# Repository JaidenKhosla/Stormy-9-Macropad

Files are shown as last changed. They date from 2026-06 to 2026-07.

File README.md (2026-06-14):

# Stormy 9 - A Macropad Designed for Simplicity
## *In today's age of mechanical keyboards, people value simplicity and customizability. The Stormy 9 allows this by having up to 16 programmable buttons, a knob to adjust volume and brightness, and an OLED display that shows off your WPM and a cute picture of my cat (non-negotiable).*

### \* *The case is mounted from the bottom. In my current setup, a top mounted case would look bad (not saying top mounted cases look ugly or anything, it just wouldn't work for my personal setup).*

## Personal Use:
####  A bit off topic, but I'm probably going to use this macropad for additional keybinds for video games (probably CS2 with their buy menu). Also, I've always desired to adjust my volume and brightness with ease as my current keyboard doesn't have a knob.

## PCB Schematic (Made with KICAD)
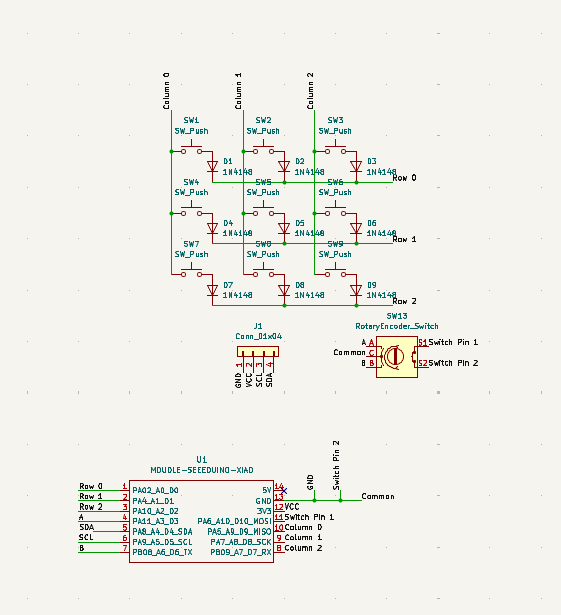
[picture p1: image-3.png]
 

#### I learned PCB schematics through ScottoKeeb's tutorial (https://youtu.be/8WXpGTIbxlQ?si=Y5YSVLcabkqrECWy). It was genuinely super helpful and I would've spent so many more hours without it.

## PCB Layout
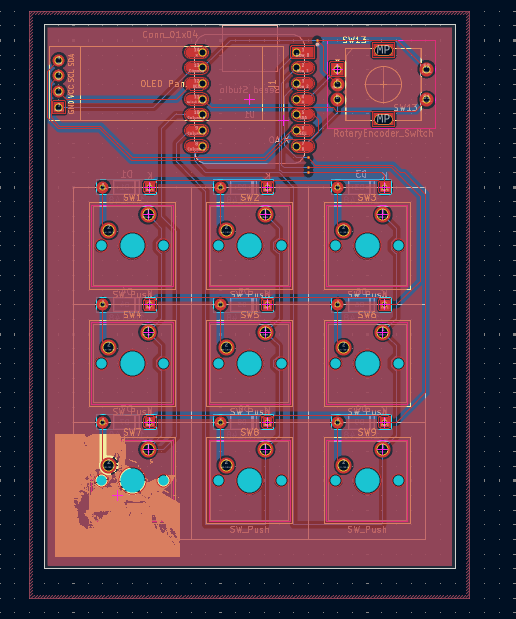
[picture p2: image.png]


## 3D Model of The Stormy 9
#### For context, I tried using Fusion-360 to design the case (like any normal person would). However, Fusion-360 refused to import STEP and STL files (I wanted to import the 3D model of my PCB for rendering and ease of modeling), forcing me to voluntarily choose Blender. Contrary to popular belief, Blender was actually super easy and useful to model the case. For anyone planning to design their case in Blender, please google what non-manifold edges are before starting (it will save you so much time in the future). To convert the models to STEP files, I utilized the open-sourced software, FreeCAD.
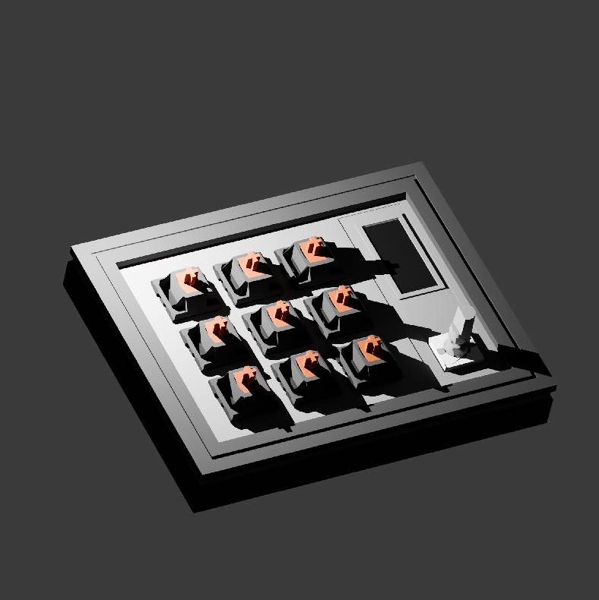
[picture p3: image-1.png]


## 3D render of the backside of the Stormy 9
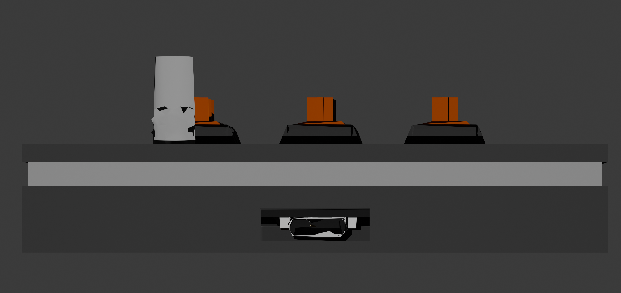
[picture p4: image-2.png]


## Firmware
### For the firmware, I utilized the open-source project, QMK. I found this to be a lot better than KMK as it's still officially maintained and gave developers a lot more granular control. It also forces you to code in C rather than Python (Take that as a bonus or a burden). 

# __Materials Needed:__
### * 1 Seeed XIAO RP2040 Microcontroller
### * 9 1N4148 Through-Hole Diodes
### * 9 MX-style Mechanical Switches
### * 1 EC11 Rotary Encoder
### * 1 0.91" 128X32 OLED Display
### * 9 Blank DSA Keycaps
### * 4 M3x16mm Screws
### * 4 M3x5x4mm Heatset Inserts
### * Sanity

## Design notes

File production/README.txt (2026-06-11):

When I was debugging the 3D models in their STEP formats with Creality Print, TOP_CASE_PRINT_V2.STEP when sliced produced something that would've messed up the entire macropad. When you import it as an STL, it slices correctly. I included the STEP file, but please use the STL file.

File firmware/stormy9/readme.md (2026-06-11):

# stormy9

stormy9

*A short description of the keyboard/project*

* Keyboard Maintainer: [Jaiden Khosla](https://github.com/JaidenKhosla)
* Hardware Supported: *The PCBs, controllers supported*
* Hardware Availability: *Links to where you can find this hardware*

Make example for this keyboard (after setting up your build environment):

    make stormy9:default

Flashing example for this keyboard:

    make stormy9:default:flash

See the [build environment setup](https://docs.qmk.fm/#/getting_started_build_tools) and the [make instructions](https://docs.qmk.fm/#/getting_started_make_guide) for more information. Brand new to QMK? Start with our [Complete Newbs Guide](https://docs.qmk.fm/#/newbs).

## Bootloader

Enter the bootloader in 3 ways:

* **Bootmagic reset**: Hold down the key at (0,0) in the matrix (usually the top left key or Escape) and plug in the keyboard
* **Physical reset button**: Briefly press the button on the back of the PCB - some may have pads you must short instead
* **Keycode in layout**: Press the key mapped to `QK_BOOT` if it is available

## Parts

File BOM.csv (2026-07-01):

Name | Quantity
Seeed XIAO RP2040 Microcontroller | 1
1N4148 Through-Hole Diodes | 9
MX-style Mechanical Switches | 9
EC11 Rotary Encoder | 1
0.91" 128x32 OLED Display | 1
Blank DSA Keycaps | 9
M3x16mm Screws | 4
M3x5x4mm Heatset Inserts | 4

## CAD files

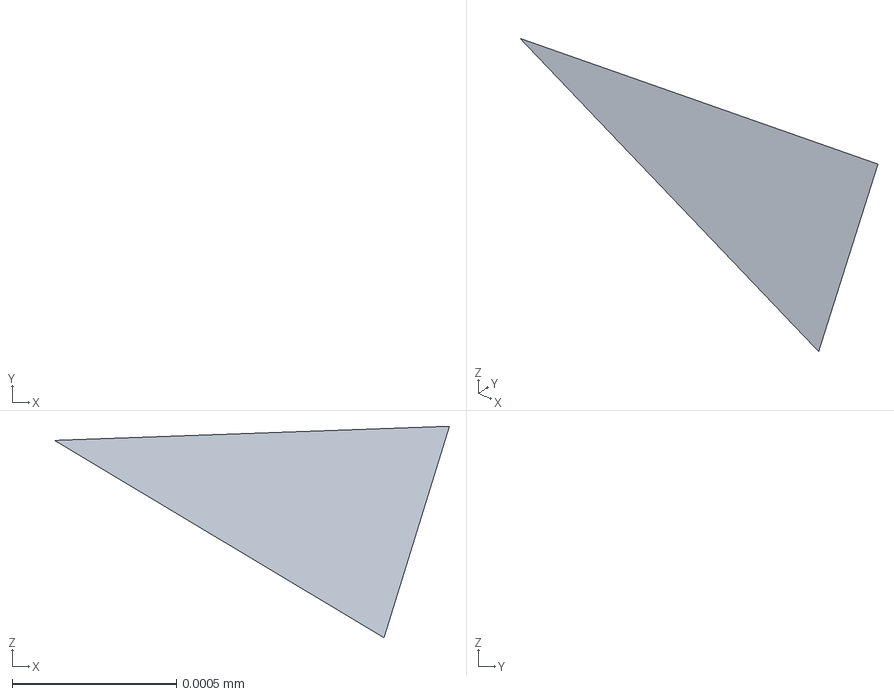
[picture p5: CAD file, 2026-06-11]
CAD/assembled_model.step
0.0012 x 0 x 0.000643 mm
Line
Line001
Line002
Line003
Line004
Line005
Line006
Line007
Line008
Wire
Line009
Line010
Line011
Line012
Line013
Line014
Line015
Line016
Line017
Line018
Line019
Line020
Line021
Line022
Line023
Line024
Line025
Line026
Line027
Line028
Line029
Line030
Line031
Line032
Line033
Line034
Wire001
Line035
Line036
Line037
Line038
Line039
Line040
Line041
Line042
Line043
Line044
Line045
Line046
Line047
Line048
Line049
Line050
Line051
Line052
Line053
Line054
Line055
Line056
Line057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

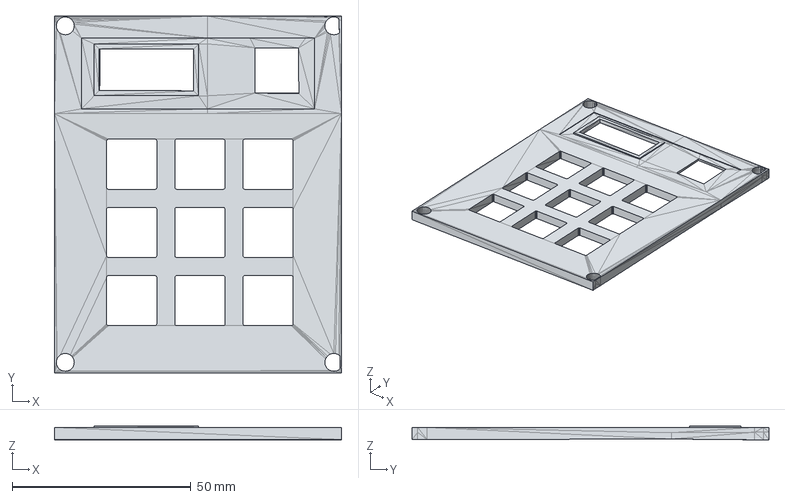
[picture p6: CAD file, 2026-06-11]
production/MACROPAD_PLATE_PRINT.step
80.2 x 99.7 x 3.82 mm

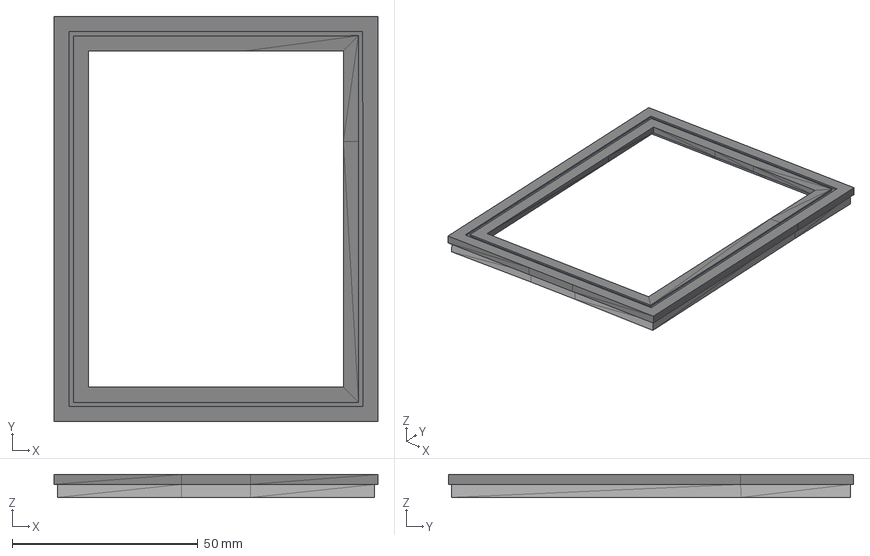
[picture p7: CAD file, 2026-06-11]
production/TOP_CASE_PRINT_V1.step
87.1 x 109.0 x 6.19 mm

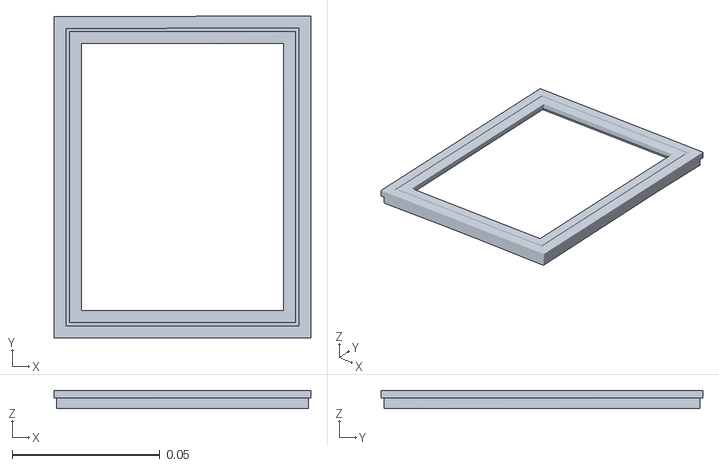
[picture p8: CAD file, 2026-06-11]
production/TOP_CASE_PRINT_V2.stl
0.0871 x 0.109 x 0.00619

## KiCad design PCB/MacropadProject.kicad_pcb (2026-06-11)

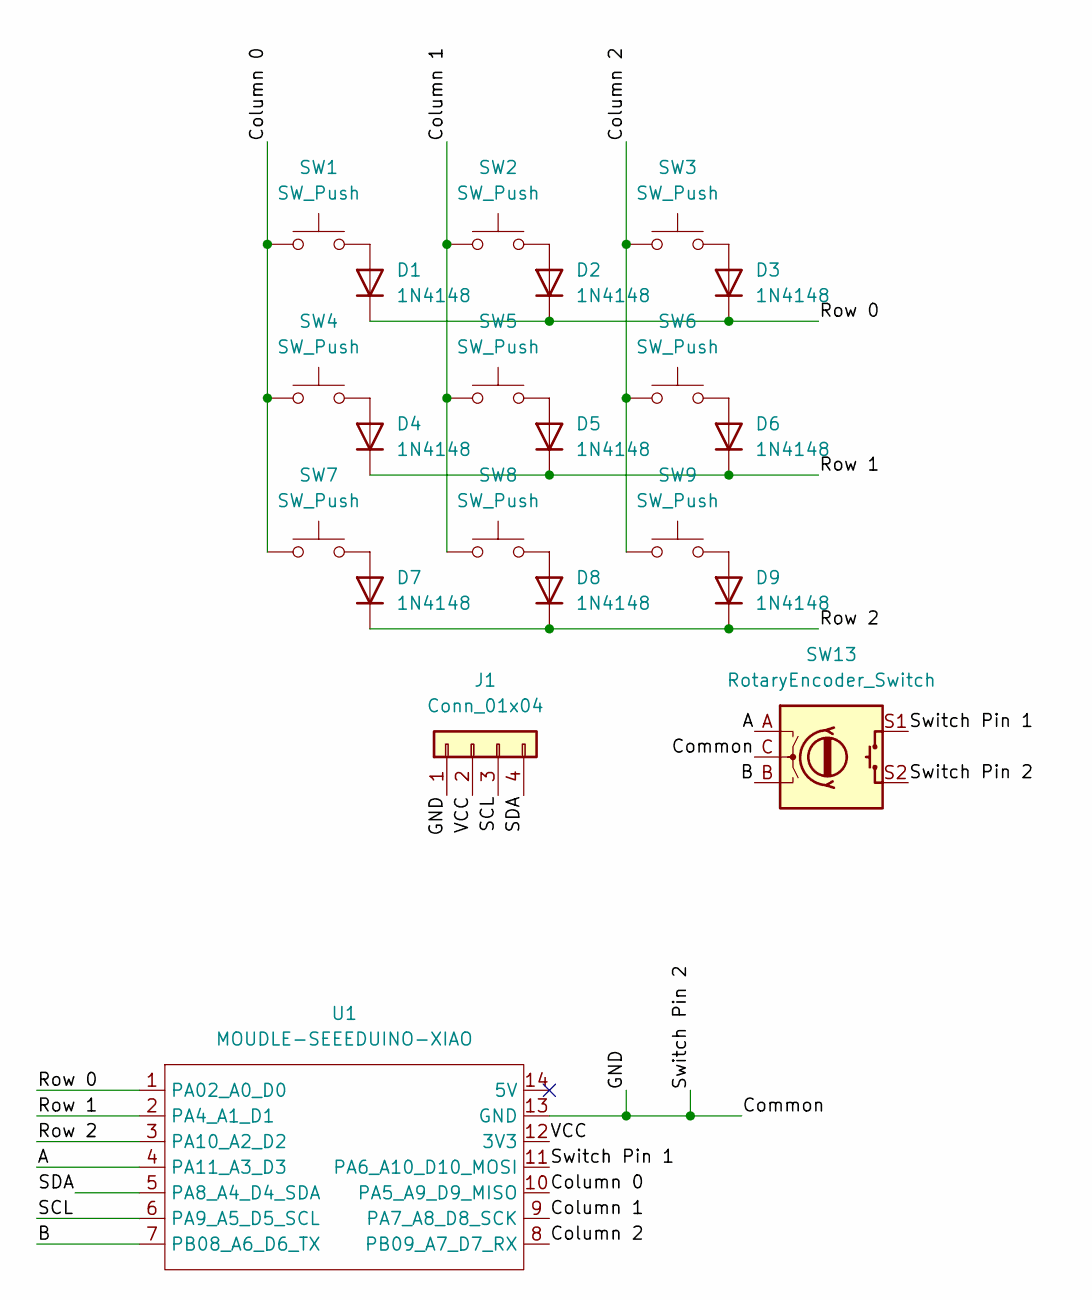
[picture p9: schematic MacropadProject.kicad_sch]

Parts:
D1, D2, D3, D4, D5, D6, D7, D8, D9: 1N4148; D_DO-35_SOD27_P7.62mm_Horizontal
J1: Conn_01x04; SSD1306-0.91-OLED-4pin-128x32
SW1, SW2, SW3, SW4, SW5, SW6, SW7, SW8, SW9: SW_Push; SW_Cherry_MX_1.00u_PCB
SW13: RotaryEncoder_Switch; RotaryEncoder_Alps_EC11E-Switch_Vertical_H20mm
U1: MOUDLE-SEEEDUINO-XIAO; XIAO-Generic-Hybrid-14P-2.54-21X17.8MM

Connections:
/A: SW13.A, U1.4 (PA11_A3_D3)
/B: SW13.B, U1.7 (PB08_A6_D6_TX)
/Column 0: SW1.1, SW4.1, SW7.1, U1.10 (PA5_A9_D9_MISO)
/Column 1: SW2.1, SW5.1, SW8.1, U1.9 (PA7_A8_D8_SCK)
/Column 2: SW3.1, SW6.1, SW9.1, U1.8 (PB09_A7_D7_RX)
/Common: J1.1, SW13.C, SW13.S2, U1.13 (GND)
/Row 0: D1.1 (K), D2.1 (K), D3.1 (K), U1.1 (PA02_A0_D0)
/Row 1: D4.1 (K), D5.1 (K), D6.1 (K), U1.2 (PA4_A1_D1)
/Row 2: D7.1 (K), D8.1 (K), D9.1 (K), U1.3 (PA10_A2_D2)
/SCL: J1.3, U1.6 (PA9_A5_D5_SCL)
/SDA: J1.4, U1.5 (PA8_A4_D4_SDA)
/Switch Pin 1: SW13.S1, U1.11 (PA6_A10_D10_MOSI)
/VCC: J1.2, U1.12 (3V3)
unnamed: D1.2 (A), SW1.2
unnamed: D2.2 (A), SW2.2
unnamed: D3.2 (A), SW3.2
unnamed: D4.2 (A), SW4.2
unnamed: D5.2 (A), SW5.2
unnamed: D6.2 (A), SW6.2
unnamed: D7.2 (A), SW7.2
unnamed: D8.2 (A), SW8.2
unnamed: D9.2 (A), SW9.2

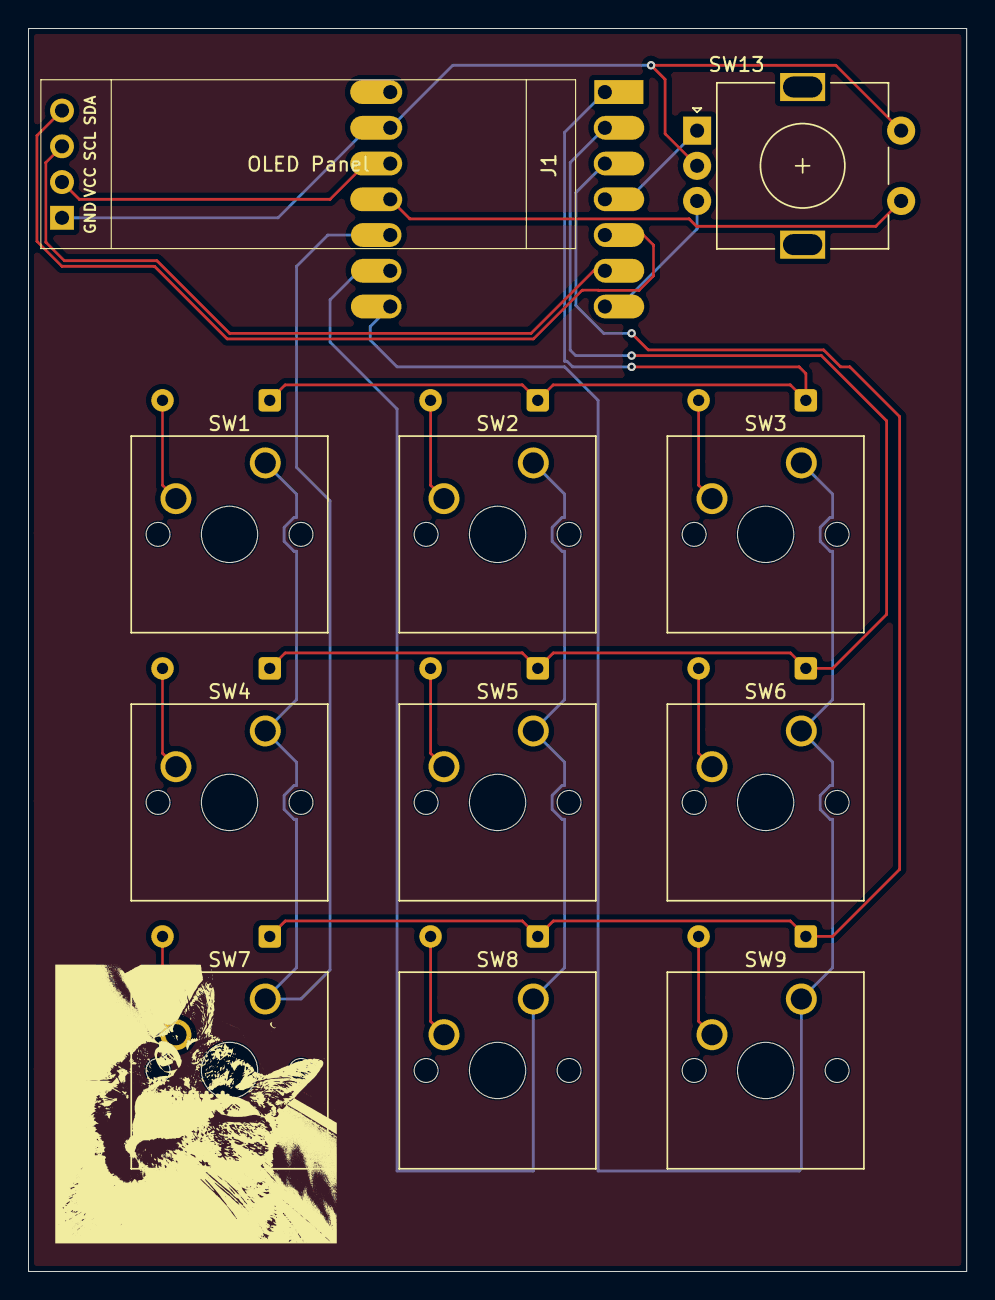
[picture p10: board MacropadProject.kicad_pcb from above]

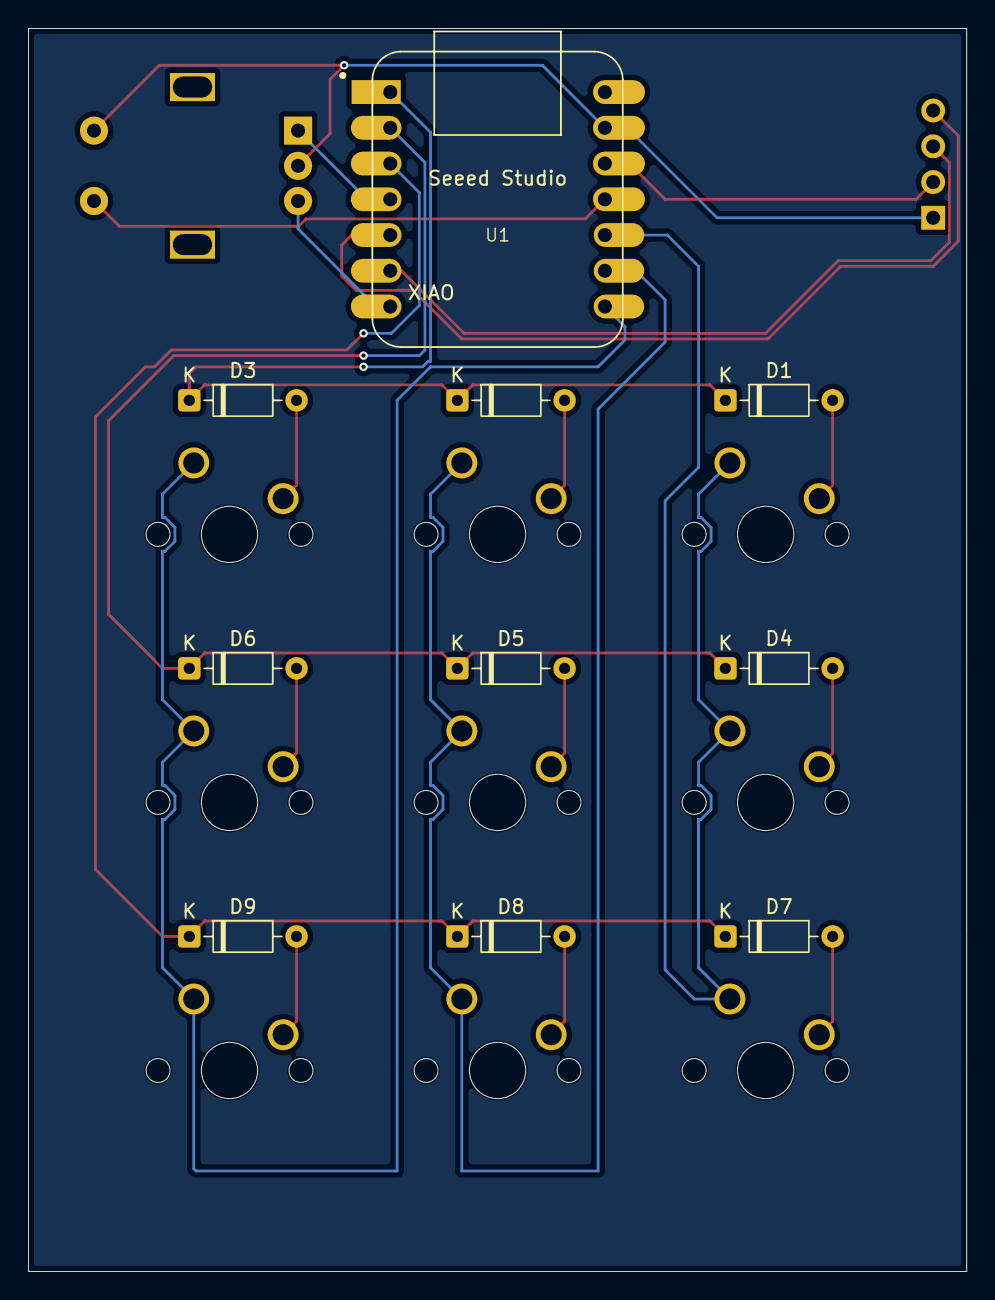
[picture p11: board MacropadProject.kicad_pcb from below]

Board: 2 copper layers, 66.7 x 88.3 mm, 21 parts (10 on the bottom side), 22 nets.

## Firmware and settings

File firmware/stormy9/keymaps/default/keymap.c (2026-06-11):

// Copyright 2023 QMK
// SPDX-License-Identifier: GPL-2.0-or-later

#define NUM_LISTENERS 1

#include <stdint.h>
#include <stdbool.h>
#include QMK_KEYBOARD_H

#if defined(ENCODER_MAP_ENABLE)
const uint16_t PROGMEM encoder_map[][NUM_ENCODERS][NUM_DIRECTIONS] = {
    [0] = { ENCODER_CCW_CW(KC_AUDIO_VOL_UP, KC_AUDIO_VOL_DOWN) },
    [1] = { ENCODER_CCW_CW(KC_BRIGHTNESS_UP, KC_BRIGHTNESS_DOWN)}
};
#endif

#if defined(OLED_ENABLE)

bool oled_task_user()
{
    static char buffer[8];

    static const char PROGMEM bitmap_data[] = {
        0x00, 0x00, 0x00, 0x02, 0x00, 0x00, 0x00, 0x00, 0x00, 0x00, 0x00, 0x00, 0x00, 0x00, 0x00, 0x00,
        0x00, 0x00, 0x00, 0x04, 0x00, 0x00, 0x00, 0x00, 0x00, 0x00, 0x00, 0x00, 0x00, 0x00, 0x00, 0x00,
        0x00, 0x00, 0x00, 0x00, 0x80, 0x00, 0x00, 0x00, 0x00, 0x00, 0x00, 0x00, 0x00, 0x00, 0x00, 0x00,
        0x00, 0x00, 0x00, 0x01, 0x80, 0x00, 0x00, 0x00, 0x00, 0x00, 0x00, 0x00, 0x00, 0x00, 0x00, 0x00,
        0x00, 0x00, 0x00, 0x17, 0x80, 0x00, 0x00, 0x00, 0x00, 0x00, 0x00, 0x00, 0x00, 0x00, 0x00, 0x00,
        0x10, 0x00, 0x00, 0x07, 0x80, 0x00, 0x00, 0x00, 0x00, 0x00, 0x00, 0x00, 0x00, 0x00, 0x00, 0x00,
        0x00, 0x02, 0x10, 0x03, 0x00, 0x00, 0x00, 0x00, 0x00, 0x00, 0x00, 0x00, 0x00, 0x00, 0x00, 0x00,
        0x10, 0x00, 0x0C, 0x03, 0x00, 0x00, 0x00, 0x00, 0x00, 0x00, 0x00, 0x00, 0x00, 0x00, 0x00, 0x00,
        0x15, 0x40, 0x58, 0x00, 0x00, 0x00, 0x00, 0x00, 0x00, 0x00, 0x00, 0x00, 0x00, 0x00, 0x00, 0x00,
        0x1E, 0x20, 0x00, 0x00, 0x00, 0x00, 0x00, 0x00, 0x00, 0x00, 0x00, 0x00, 0x00, 0x00, 0x00, 0x00,
        0x1E, 0x70, 0x00, 0xE0, 0x00, 0x00, 0x00, 0x00, 0x00, 0x00, 0x00, 0x00, 0x00, 0x00, 0x00, 0x00,
        0x1F, 0xF0, 0x03, 0xFC, 0x00, 0x00, 0x00, 0x00, 0x00, 0x00, 0x00, 0x00, 0x00, 0x00, 0x00, 0x00,
        0x03, 0xF0, 0x42, 0x04, 0x00, 0x00, 0x00, 0x00, 0x00, 0x00, 0x00, 0x00, 0x00, 0x00, 0x00, 0x00,
        0x08, 0x70, 0xE0, 0x08, 0x00, 0x00, 0x00, 0x00, 0x00, 0x00, 0x00, 0x00, 0x00, 0x00, 0x00, 0x00,
        0x08, 0xA0, 0xA0, 0xB0, 0x00, 0x00, 0x00, 0x00, 0x00, 0x00, 0x00, 0x00, 0x00, 0x00, 0x00, 0x00,
        0x17, 0xE0, 0x00, 0x40, 0x00, 0x00, 0x00, 0x00, 0x00, 0x00, 0x00, 0x00, 0x00, 0x00, 0x00, 0x00,
        0x1D, 0x80, 0x01, 0x00, 0x00, 0x00, 0x00, 0x00, 0x00, 0x00, 0x00, 0x00, 0x00, 0x00, 0x00, 0x00,
        0x1F, 0x80, 0x00, 0x60, 0x00, 0x00, 0x00, 0x00, 0x00, 0x00, 0x00, 0x00, 0x00, 0x00, 0x00, 0x00,
        0x1F, 0x00, 0x00, 0x47, 0x40, 0x00, 0x00, 0x00, 0x00, 0x00, 0x00, 0x00, 0x00, 0x00, 0x00, 0x00,
        0x1F, 0x00, 0x00, 0x38, 0x40, 0x00, 0x00, 0x00, 0x00, 0x00, 0x00, 0x00, 0x00, 0x00, 0x00, 0x00,
        0x1C, 0x00, 0x00, 0x00, 0x00, 0x00, 0x00, 0x00, 0x00, 0x00, 0x00, 0x00, 0x00, 0x00, 0x00, 0x00,
        0x00, 0x0F, 0x18, 0x00, 0x00, 0x00, 0x00, 0x00, 0x00, 0x00, 0x00, 0x00, 0x00, 0x00, 0x00, 0x00,
        0x01, 0xE7, 0x38, 0x00, 0x00, 0x00, 0x00, 0x00, 0x00, 0x00, 0x00, 0x00, 0x00, 0x00, 0x00, 0x00,
        0x01, 0x76, 0xF8, 0x00, 0x00, 0x00, 0x00, 0x00, 0x00, 0x00, 0x00, 0x00, 0x00, 0x00, 0x00, 0x00,
        0x1F, 0xFC, 0xFE, 0xC0, 0x01, 0x90, 0x00, 0x01, 0x98, 0x00, 0x00, 0x00, 0x00, 0x00, 0x00, 0x00,
        0x1B, 0xF9, 0xFC, 0x00, 0x02, 0x50, 0x00, 0x02, 0x68, 0x00, 0x00, 0x00, 0x00, 0x00, 0x00, 0x00,
        0x1F, 0xFF, 0xFF, 0xE0, 0x41, 0x3B, 0xBB, 0xEE, 0x64, 0x00, 0x00, 0x00, 0x00, 0x00, 0x00, 0x00,
        0x1F, 0xFF, 0xFF, 0x06, 0x20, 0x92, 0x73, 0x5A, 0x5C, 0x00, 0x00, 0x00, 0x00, 0x00, 0x00, 0x00,
        0x1F, 0xFD, 0xFE, 0x4C, 0xA2, 0x52, 0x63, 0x5A, 0x88, 0x00, 0x00, 0x00, 0x00, 0x00, 0x00, 0x00,
        0x1F, 0xFF, 0xFC, 0x11, 0x81, 0x9D, 0xA3, 0x51, 0xB8, 0x00, 0x00, 0x00, 0x00, 0x00, 0x00, 0x00,
        0x1F, 0xFF, 0xFC, 0x00, 0x60, 0x00, 0x00, 0x10, 0x00, 0x00, 0x00, 0x00, 0x00, 0x00, 0x00, 0x00,
        0x1F, 0xFF, 0xFF, 0x00, 0x00, 0x00, 0x00, 0x00, 0x00, 0x00, 0x00, 0x00, 0x00, 0x00, 0x00, 0x00,
    };

    oled_set_cursor(0,0);

    oled_write_raw_P(bitmap_data, sizeof(bitmap_data));

    oled_set_cursor(76, 24);

    snprintf(buffer, sizeof(buffer), "WPM: %d", get_current_wpm());

    oled_write_ln(buffer, false);

    return false;
}

#endif

const uint8_t PROGMEM specialKeys[NUM_LISTENERS] = {
    GP3,
};

const uint16_t PROGMEM keymaps[][MATRIX_ROWS][MATRIX_COLS] = {
    /*
     * ┌───┬───┬───┐
     * │ A │ B │ C │
     * ├───┼───┼───┤
     * │ D │ E │ F │
     * ├───┼───┼───┤
     * │ G │ H │ I │
     * └───┴───┴───┘
     */
    [0] = LAYOUT_ortho_3x3(
        QK_PROGRAMMABLE_BUTTON_1,    QK_PROGRAMMABLE_BUTTON_2,    QK_PROGRAMMABLE_BUTTON_3,
        QK_PROGRAMMABLE_BUTTON_4,    QK_PROGRAMMABLE_BUTTON_5,    QK_PROGRAMMABLE_BUTTON_6,
        MO(1),    QK_PROGRAMMABLE_BUTTON_7,    QK_PROGRAMMABLE_BUTTON_8
    ),

    [1] = LAYOUT_ortho_3x3(
        QK_PROGRAMMABLE_BUTTON_9, QK_DEBUG_TOGGLE, QK_BOOTLOADER,
        QK_PROGRAMMABLE_BUTTON_10, QK_PROGRAMMABLE_BUTTON_11, QK_PROGRAMMABLE_BUTTON_12,
        QK_PROGRAMMABLE_BUTTON_13, QK_PROGRAMMABLE_BUTTON_14, QK_PROGRAMMABLE_BUTTON_15
    )
};



void onPinActivation(uint16_t key)
{
    switch (key)
    {
    case GP3:
        uint8_t current_layer = get_highest_layer(layer_state);

        switch (current_layer)
        {
        case 0:
            tap_code(KC_AUDIO_MUTE);
            break;

        case 1:
            tap_code(KC_WWW_SEARCH);
            break;
        }

        break;
    }
}

void matrix_scan_user(void)
{
    static bool last_state[NUM_LISTENERS] = { false };

    for(int i = 0; i < NUM_LISTENERS; i++)
    {
        if(last_state[i]) continue;

        if(gpio_read_pin(specialKeys[i]))
        {
            onPinActivation(specialKeys[i]);
        }

    }
}
